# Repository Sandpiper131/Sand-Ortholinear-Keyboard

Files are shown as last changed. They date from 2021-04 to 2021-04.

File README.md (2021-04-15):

# [ Description ]
The Sand Ortholinear is a QWERTY style keyboard with 47 individually programmable keys. The
keyboard is powered by an ATMEGA32U4 microcontroller running the QMK open source keyboard
firmware. The goal of this project was to design a keyboard which is compact and durable while
having a simple case.

# [ Design Requirements ]
-Compact/Portable  
-Cherry MX Compatible  
-Ortholinear QWERTY (Grid) Layout with 2U spacebar  
-No visible components on top side of board  
-minimize trace presence on visible portions of top PCB  
-Sandwich style case PCB|ACRYLIC|PCB held together with M3 Screws  
-USB-C Connector  
-Sturdy Construction  

# [ Gallery ]
## Renders:
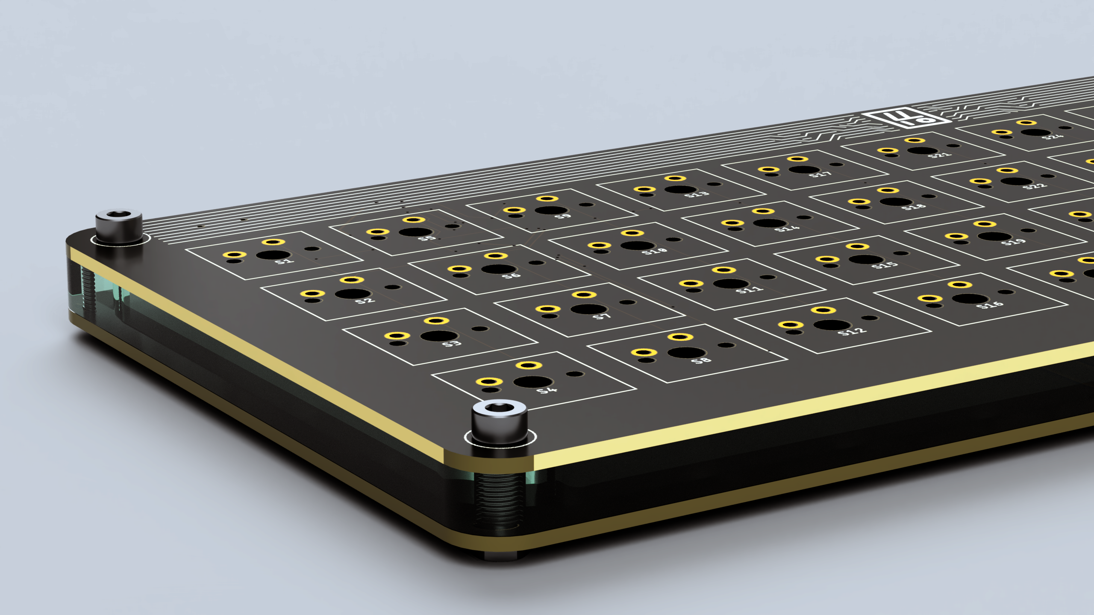
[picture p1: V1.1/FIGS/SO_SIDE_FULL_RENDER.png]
sand ortho render (side)
  
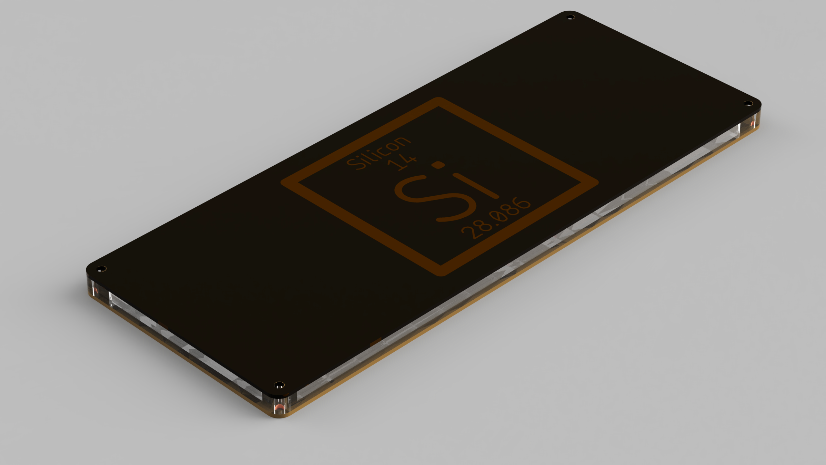
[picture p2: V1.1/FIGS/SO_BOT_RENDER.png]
sand ortho render (bottom)
  

## Schematics:
Sand Ortho V1.1 Schematic

## Board Layout:
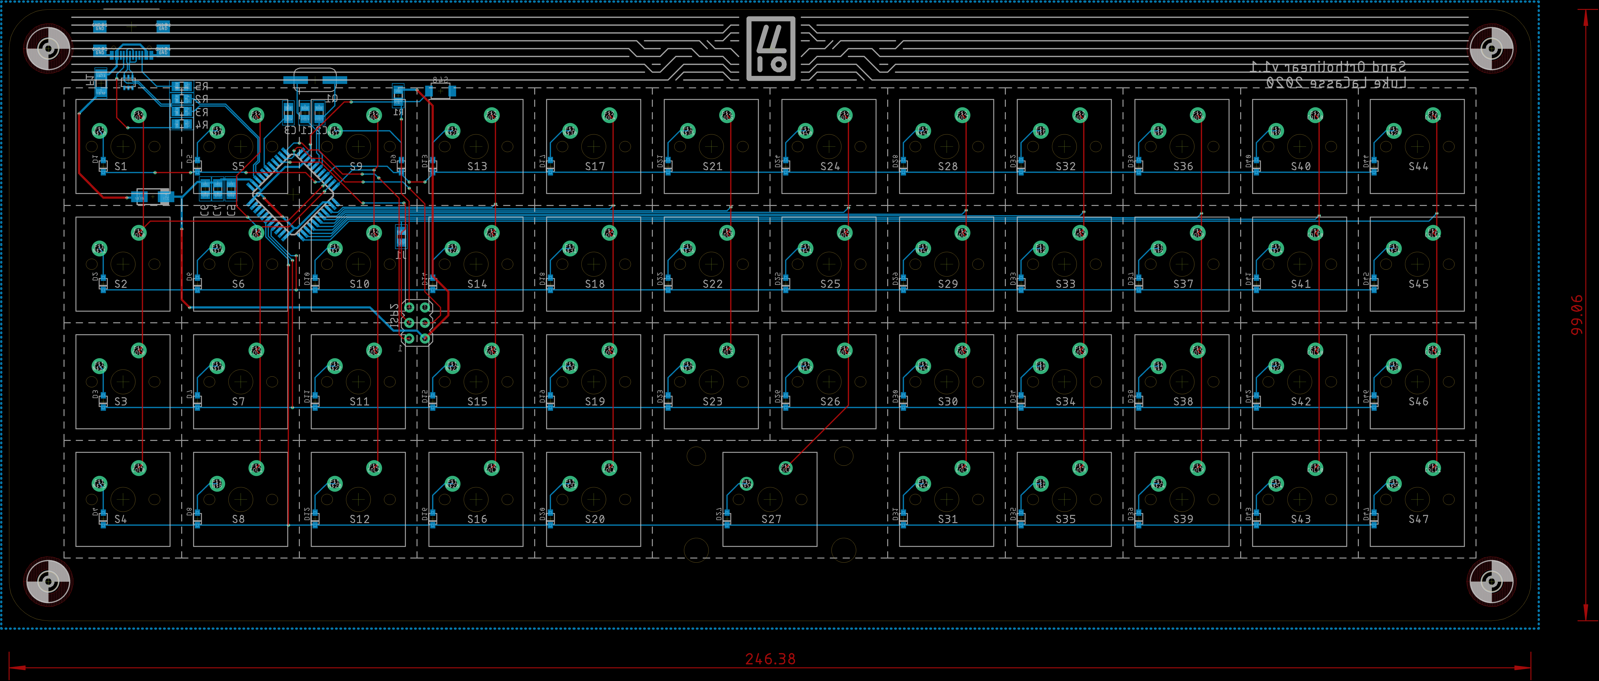
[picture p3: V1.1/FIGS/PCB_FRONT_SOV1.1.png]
Board Layout (Front 1)

Board Layout (Front 2)
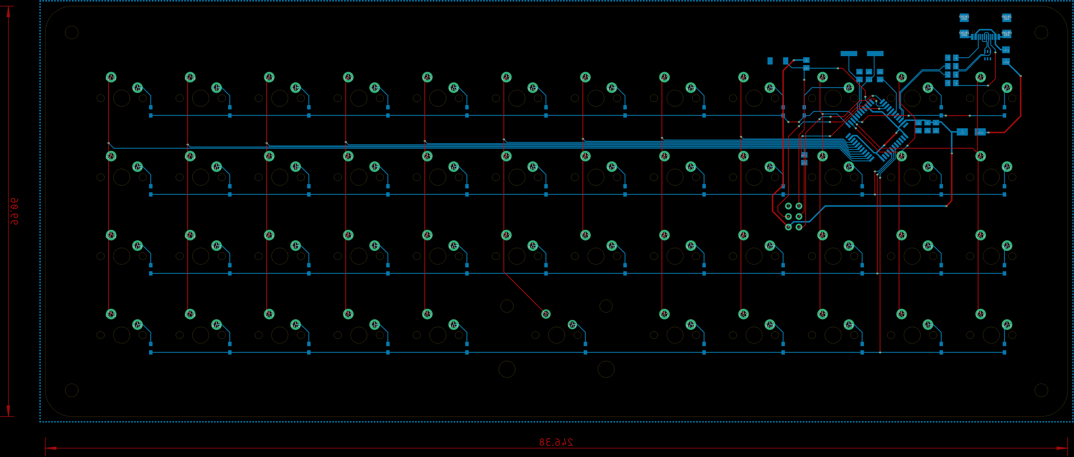
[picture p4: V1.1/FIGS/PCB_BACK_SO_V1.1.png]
Board Layout (Back 0)

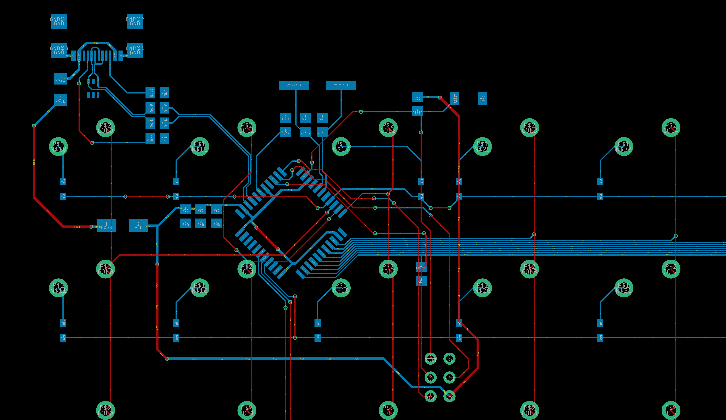
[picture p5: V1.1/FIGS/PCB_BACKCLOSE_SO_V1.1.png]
Board Close Up (Back)


## Pictures:
Sand Ortho Shot 2
Sand Ortho Shot 1

# [ Version History ]
## QMKDEVBRD
The QMK Development Board is a 3x3 Cherry MX-Compatible keypad used to
prototype a keyboard circuit prior to building a larger and more expensive keyboard. 
In addition to the basic microcontroller circuit with ISP and USB connectivity a 
prototyping area with breakouts for unused uC pins is included. Doing so 
makes this board not only a prototype for a final keyboard design, but also
a useful tool for contributing to the QMK Firmware project in the future.
The QMK Development Board functions as expected and works flawlessly with 
the QMK firmware. 

## Sand v1.0
Error in USB-C Circuit, no resistors for orientation, D+/D- not shorted 
to respective pair; USB connectivity non-functional. Added protection
circuit with Schottkey Diode and PTC fuse. Diodes are too small and
difficult to solder resulting in feedback in keyboard matrix. Crystal
Oscillator is also too small and impossible to solder by hand; Resolved
using a through hole crystal soldered onto pads. 

Changing focus to the mechanical/visual design of the keyboard is a simple
yet elegant PCB and Acrylic sandwich all held togetherwith M3 bolts and nuts.  
The resulting keyboard exceeded expectations and is very rigid, low-profile,
and provides ample protection from dust and debris.

## Sand v1.1
Added larger surface mount crystal oscillator and corrected above mentioned
flaws in the USB-C circuit. Opted not to change the diodes
as this was a minor revision and the part had already been ordered in excess.

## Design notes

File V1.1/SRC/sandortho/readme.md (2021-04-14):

# sandortho

sandortho

The sand ortholinear keyboard was inpired by silicon, the element used to make semiconductor materials. The keyboard has 47 keys laid out in an ortholinear grid with a 2U spacebar. The board can be assembled with standoffs in between the backplate, the keyboard can be as short as 7.2mm tall (excluding switches and keycpas) or as tall as ~9.5mm with a 1/4" piece of acrylic sandwiched in between. I worked on this project from the end of July 2020 to September 2020.

* Keyboard Maintainer: [Luke LaCasse](https://github.com/Sandpiper131)
* Hardware Supported: ATMEGA32-U4
* Hardware Availability: This is custom hardware and will not be run a second time, only five are in existence.

Make example for this keyboard (after setting up your build environment):

    make sandortho:default

See the [build environment setup](https://docs.qmk.fm/#/getting_started_build_tools) and the [make instructions](https://docs.qmk.fm/#/getting_started_make_guide) for more information. Brand new to QMK? Start with our [Complete Newbs Guide](https://docs.qmk.fm/#/newbs).

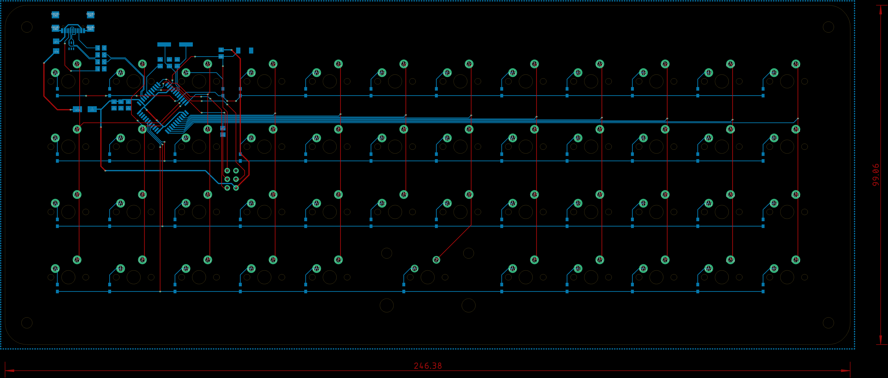
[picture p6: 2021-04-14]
V1.1/FIGS/PCB_FRONT1_SOV1.1.png

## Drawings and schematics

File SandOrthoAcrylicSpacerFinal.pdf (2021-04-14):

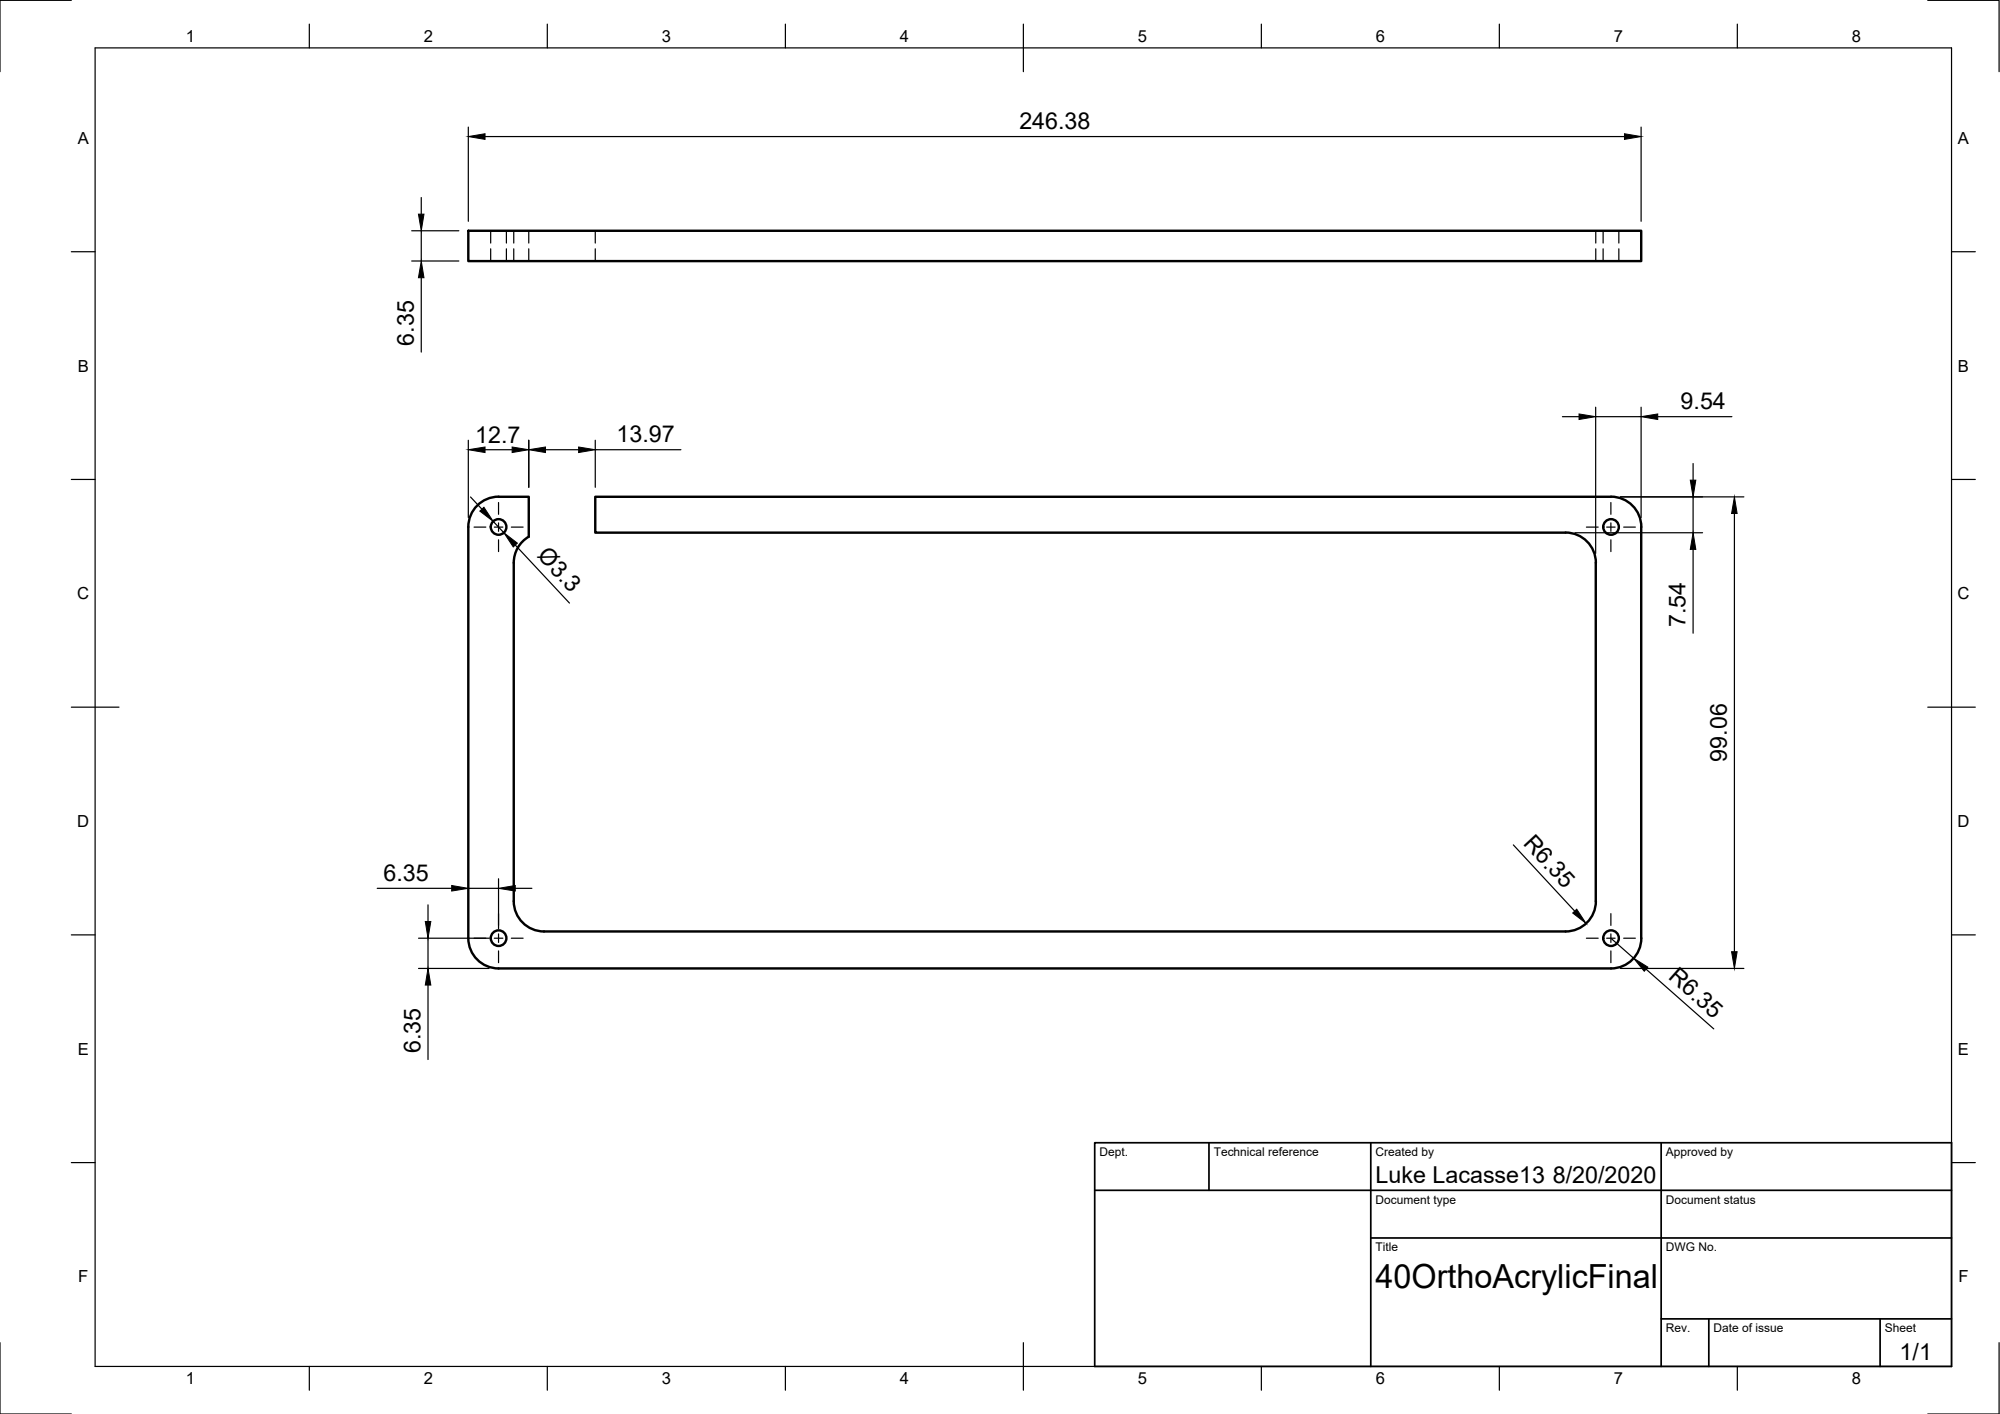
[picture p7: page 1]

Dept. | Technical reference | Created by Luke Lacasse13 8/20/2020 | Approved by

Document type | Document status

Title 40OrthoAcrylicFinal | DWG No.

Rev. | Date of issue | Sheet 1/1

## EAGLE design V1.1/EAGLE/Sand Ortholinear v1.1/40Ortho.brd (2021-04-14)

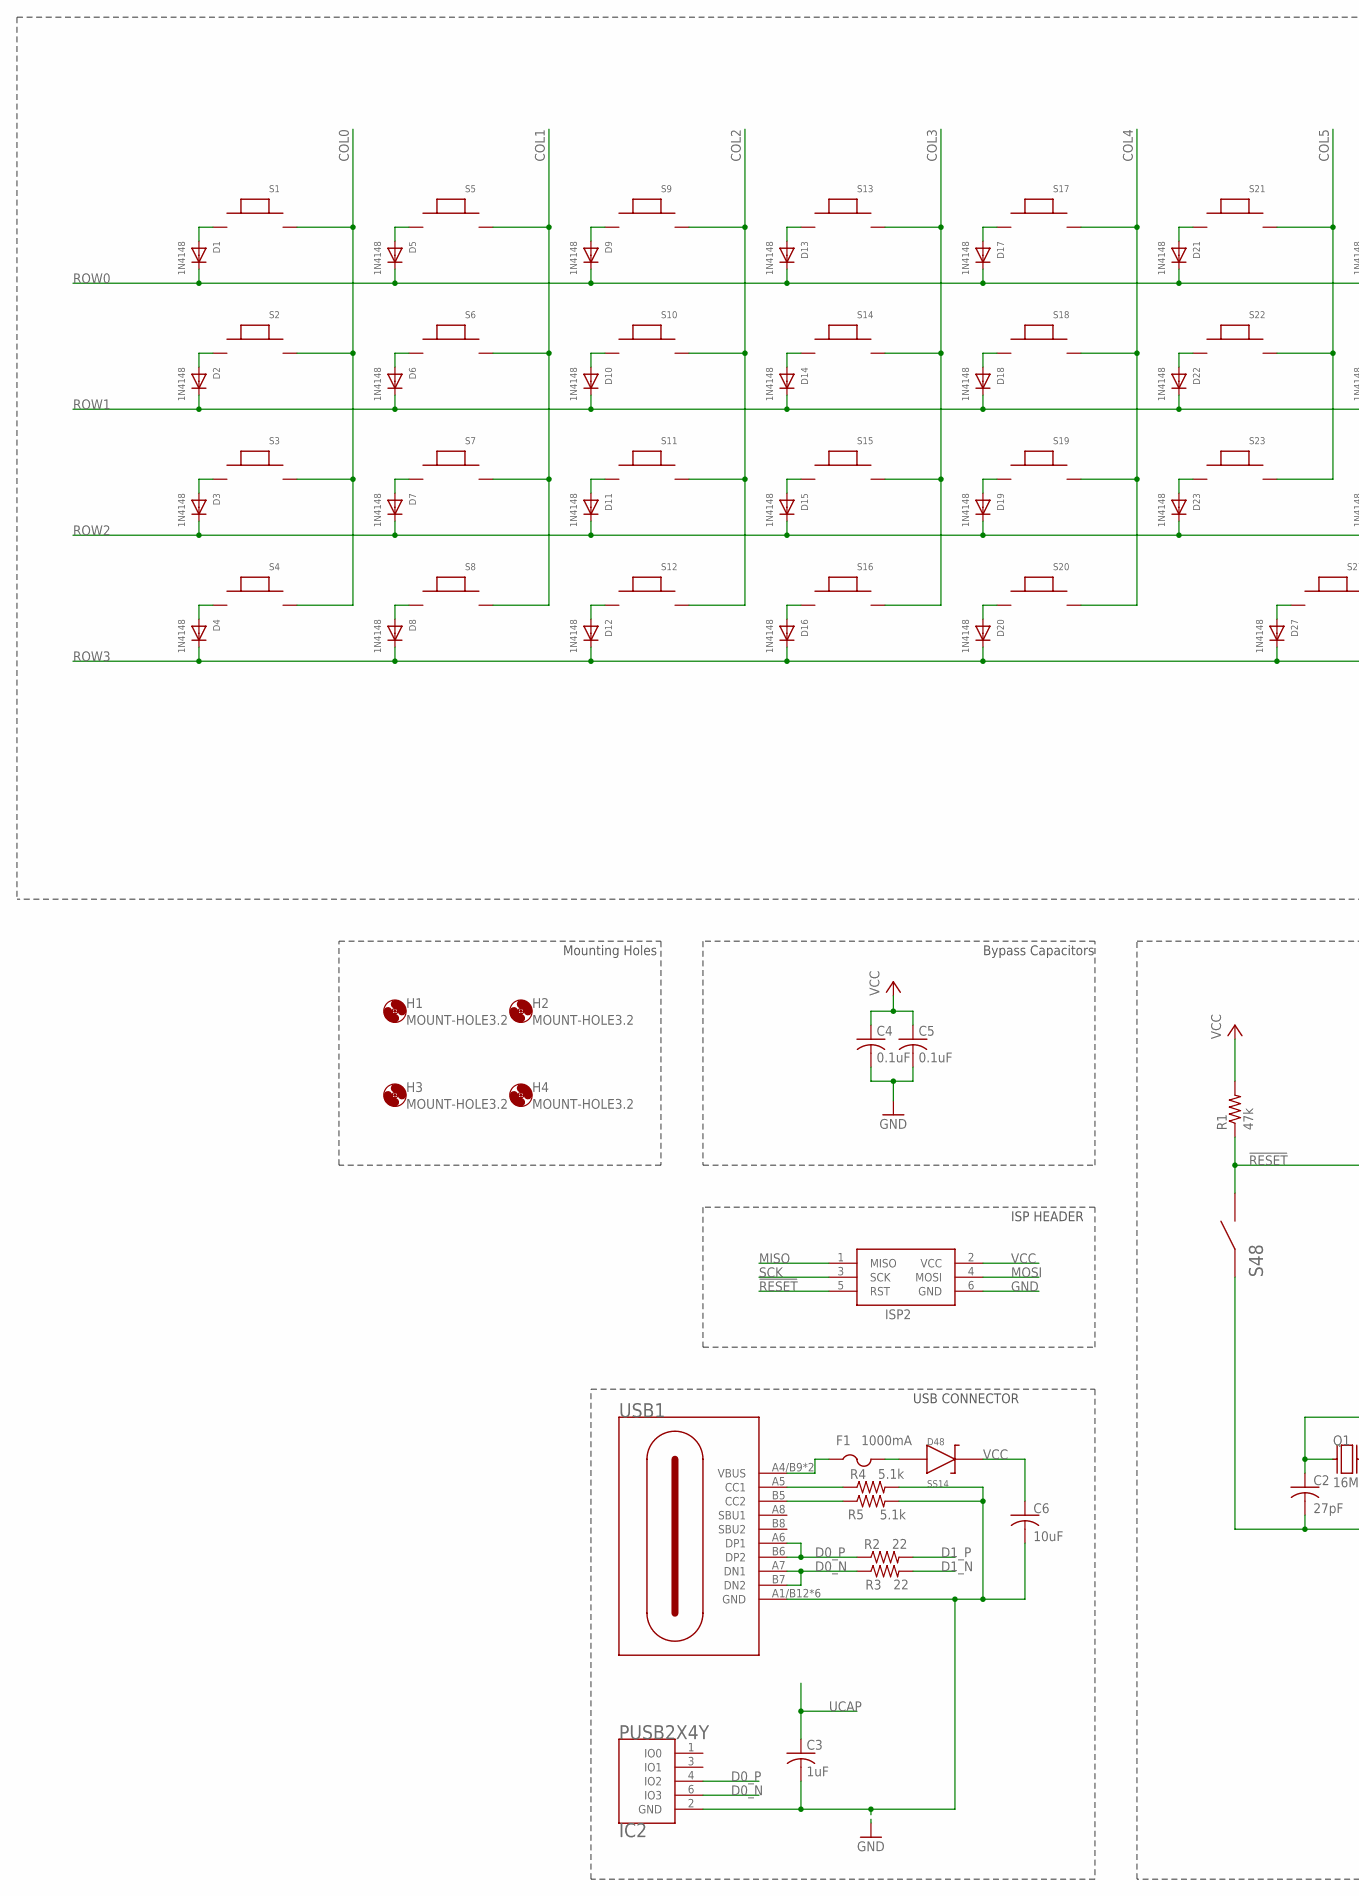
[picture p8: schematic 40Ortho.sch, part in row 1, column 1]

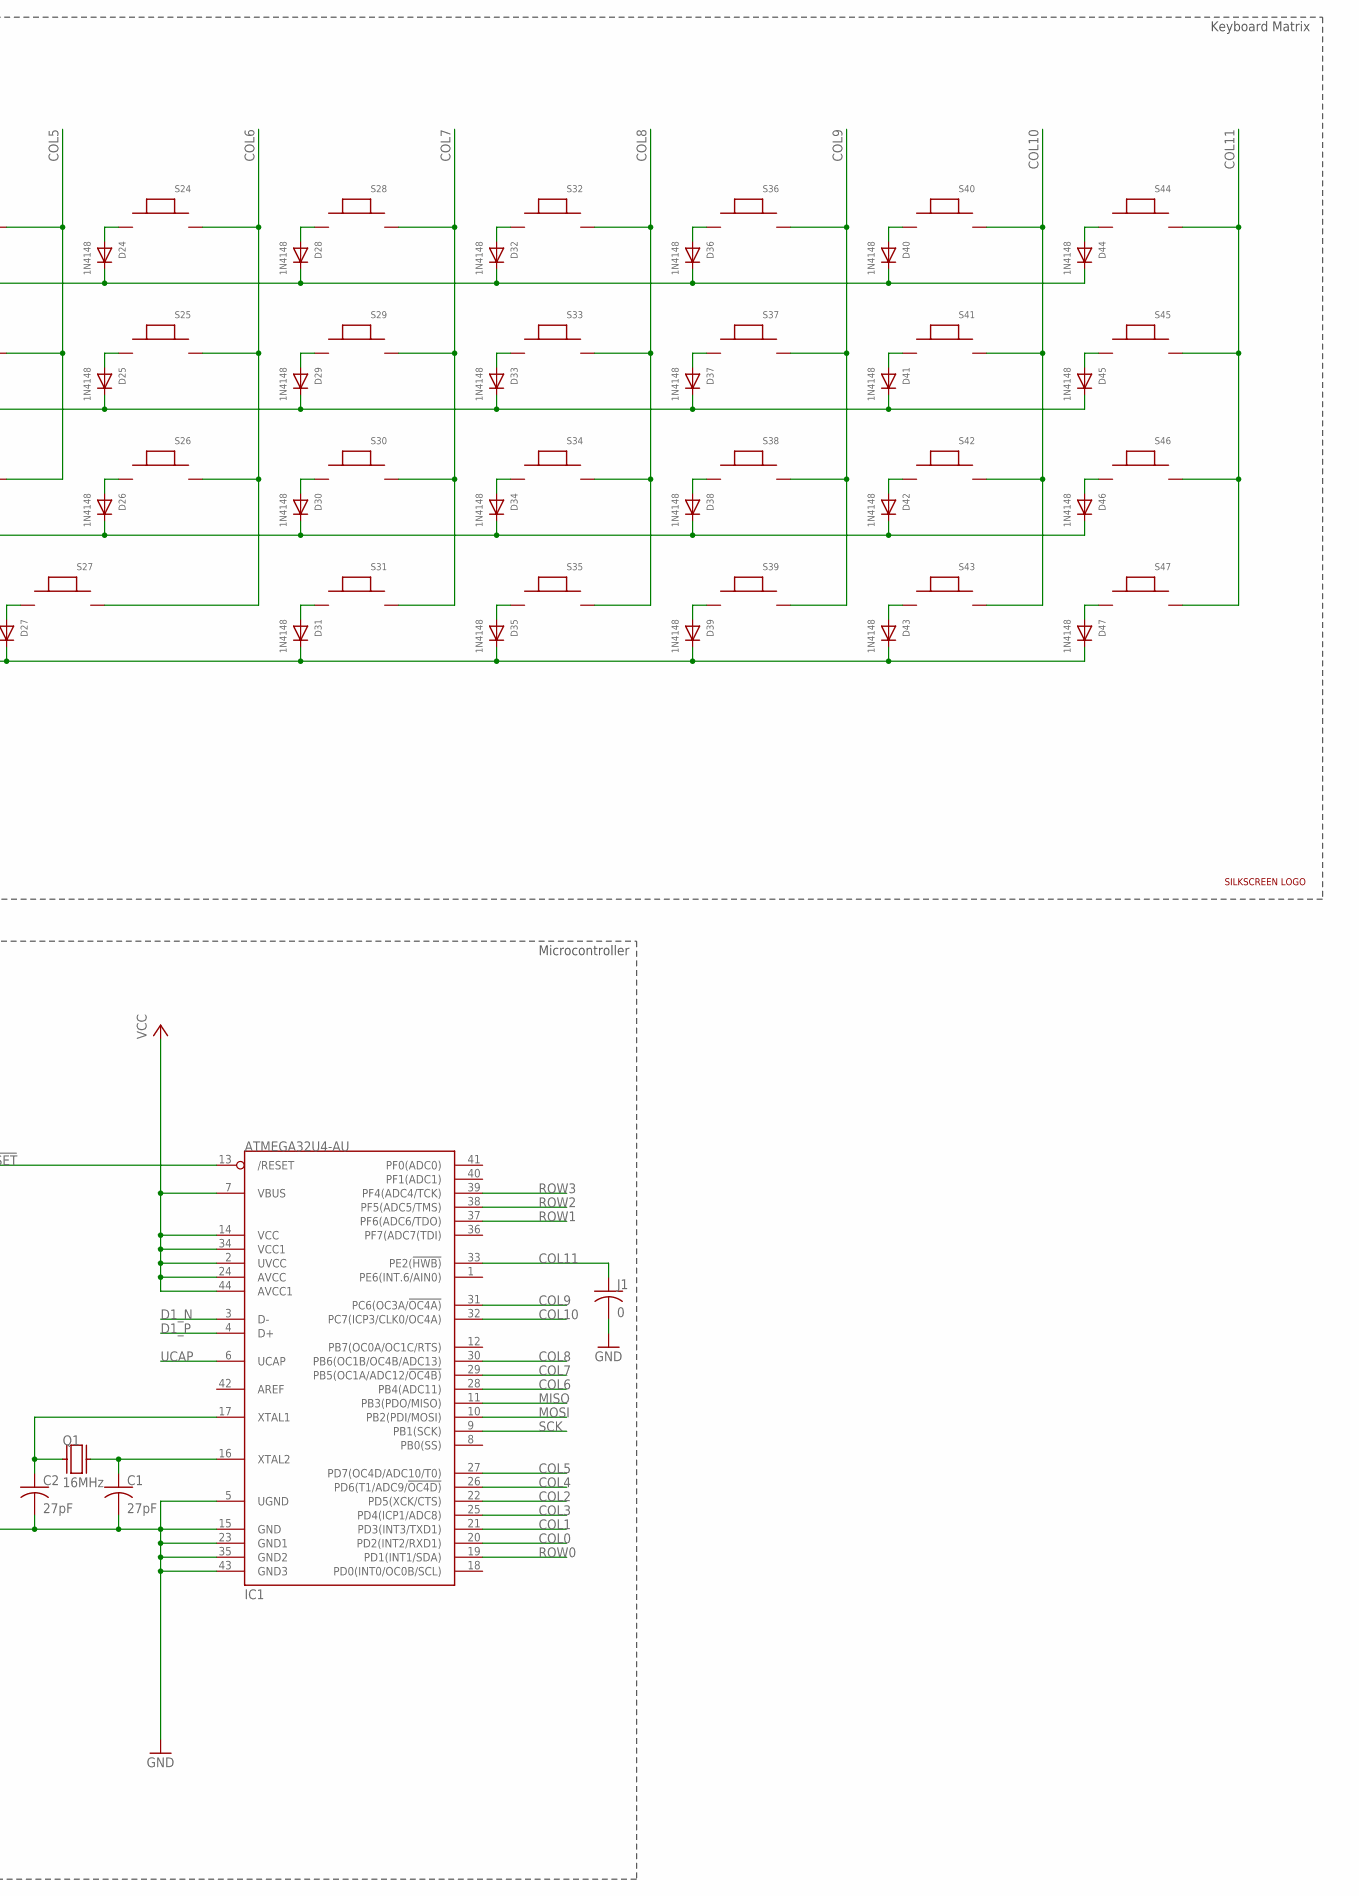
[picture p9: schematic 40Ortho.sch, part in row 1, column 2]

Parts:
C1, C2: 27pF; C0805
C3: 1uF; C0805
C4, C5: 0.1uF; C0805
C6: 10uF; C0805
D1, D2, D3, D4, D5, D6, D7, D8, D9, D10, D11, D12, D13, D14, D15, D16, D17, D18, D19, D20, D21, D22, D23, D24, D25, D26, D27, D28, D29, D30, D31, D32, D33, D34, D35, D36, D37, D38, D39, D40, D41, D42, D43, D44, D45, D46, D47: 1N4148; SOD-323F
D48: SS14; DO-214AC
F1: 1000mA; R1206
H1, H2, H3, H4: MOUNT-HOLE3.2; 3,2
IC1: ATMEGA32U4-AU; TQFP44
IC2: PUSB2X4Y; SOT363
ISP2: AVRISP-6; AVRISP
J1: 0; C0805
Q1: 16MHz; ABLS7M2
R1: 47k; R0805
R2, R3: 22; R0805
R4, R5: 5.1k; R0805
S1, S2, S3, S4, S5, S6, S7, S8, S9, S10, S11, S12, S13, S14, S15, S16, S17, S18, S19, S20, S21, S22, S23, S24, S25, S26, S28, S29, S30, S31, S32, S33, S34, S35, S36, S37, S38, S39, S40, S41, S42, S43, S44, S45, S46, S47: MX_SMD_1U; MX_SMD
S27: MX_SMD_2UH; MX_SMD2U
S48: B3U-1000P
U$1: LOGO
USB1: USBC_16PINSMD

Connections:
!RESET: IC1.13 (/RESET), ISP2.5 (RST), R1.1, S48.2
COL0: IC1.20 (PD2(INT2/RXD1)), S1.P$2, S2.P$2, S3.P$2, S4.P$2
COL1: IC1.21 (PD3(INT3/TXD1)), S5.P$2, S6.P$2, S7.P$2, S8.P$2
COL2: IC1.22 (PD5(XCK/CTS)), S9.P$2, S10.P$2, S11.P$2, S12.P$2
COL3: IC1.25 (PD4(ICP1/ADC8)), S13.P$2, S14.P$2, S15.P$2, S16.P$2
COL4: IC1.26 (PD6(T1/ADC9/!OC4D)), S17.P$2, S18.P$2, S19.P$2, S20.P$2
COL5: IC1.27 (PD7(OC4D/ADC10/T0)), S21.P$2, S22.P$2, S23.P$2
COL6: IC1.28 (PB4(ADC11)), S24.P$2, S25.P$2, S26.P$2, S27.P$2
COL7: IC1.29 (PB5(OC1A/ADC12/!OC4B)), S28.P$2, S29.P$2, S30.P$2, S31.P$2
COL8: IC1.30 (PB6(OC1B/OC4B/ADC13)), S32.P$2, S33.P$2, S34.P$2, S35.P$2
COL9: IC1.31 (PC6(OC3A/!OC4A)), S36.P$2, S37.P$2, S38.P$2, S39.P$2
COL10: IC1.32 (PC7(ICP3/CLK0/OC4A)), S40.P$2, S41.P$2, S42.P$2, S43.P$2
COL11: IC1.33 (PE2(!HWB)), J1.1, S44.P$2, S45.P$2, S46.P$2, S47.P$2
D0_N: IC2.6 (IO3), R3.1, USB1.A7 (DN1), USB1.B7 (DN2)
D0_P: IC2.4 (IO2), R2.1, USB1.A6 (DP1), USB1.B6 (DP2)
D1_N: IC1.3 (D-), R3.2
D1_P: IC1.4 (D+), R2.2
GND: C1.2, C2.2, C3.2, C4.2, C5.2, C6.2, IC1.5 (UGND), IC1.15 (GND), IC1.23 (GND1), IC1.35 (GND2), IC1.43 (GND3), IC2.2 (GND), ISP2.6 (GND), J1.2, R4.2, R5.2, S48.1, USB1.A1/B12 (GND), USB1.B1/A12 (GND), USB1.GND@1 (GND), USB1.GND@2 (GND), USB1.GND@3 (GND), USB1.GND@4 (GND)
MISO: IC1.11 (PB3(PDO/MISO)), ISP2.1 (MISO)
MOSI: IC1.10 (PB2(PDI/MOSI)), ISP2.4 (MOSI)
unnamed: D32.A, S32.P$1
unnamed: D33.A, S33.P$1
unnamed: D34.A, S34.P$1
unnamed: D35.A, S35.P$1
unnamed: D36.A, S36.P$1
unnamed: D37.A, S37.P$1
unnamed: D38.A, S38.P$1
unnamed: D8.A, S8.P$1
unnamed: D40.A, S40.P$1
unnamed: D1.A, S1.P$1
unnamed: D2.A, S2.P$1
unnamed: D3.A, S3.P$1
unnamed: D4.A, S4.P$1
unnamed: D41.A, S41.P$1
unnamed: D5.A, S5.P$1
unnamed: D6.A, S6.P$1
unnamed: D9.A, S9.P$1
unnamed: D10.A, S10.P$1
unnamed: D7.A, S7.P$1
unnamed: D12.A, S12.P$1
unnamed: D42.A, S42.P$1
unnamed: D11.A, S11.P$1
unnamed: F1.1, USB1.A4/B9 (VBUS), USB1.B4/A9 (VBUS)
unnamed: D39.A, S39.P$1
unnamed: D13.A, S13.P$1
unnamed: D14.A, S14.P$1
unnamed: D15.A, S15.P$1
unnamed: D16.A, S16.P$1
unnamed: D44.A, S44.P$1
unnamed: D17.A, S17.P$1
unnamed: D18.A, S18.P$1
unnamed: D19.A, S19.P$1
unnamed: D20.A, S20.P$1
unnamed: D45.A, S45.P$1
unnamed: D21.A, S21.P$1
unnamed: D22.A, S22.P$1
unnamed: D23.A, S23.P$1
unnamed: D48.1 (ANODE), F1.2
unnamed: D46.A, S46.P$1
unnamed: D24.A, S24.P$1
unnamed: D25.A, S25.P$1
unnamed: D26.A, S26.P$1
unnamed: R4.1, USB1.A5 (CC1)
unnamed: D28.A, S28.P$1
unnamed: D29.A, S29.P$1
unnamed: D30.A, S30.P$1
unnamed: D31.A, S31.P$1
unnamed: R5.1, USB1.B5 (CC2)
unnamed: D27.A, S27.P$1
unnamed: D43.A, S43.P$1
unnamed: D47.A, S47.P$1
ROW0: D1.C, D5.C, D9.C, D13.C, D17.C, D21.C, D24.C, D28.C, D32.C, D36.C, D40.C, D44.C, IC1.19 (PD1(INT1/SDA))
ROW1: D2.C, D6.C, D10.C, D14.C, D18.C, D22.C, D25.C, D29.C, D33.C, D37.C, D41.C, D45.C, IC1.37 (PF6(ADC6/TDO))
ROW2: D3.C, D7.C, D11.C, D15.C, D19.C, D23.C, D26.C, D30.C, D34.C, D38.C, D42.C, D46.C, IC1.38 (PF5(ADC5/TMS))
ROW3: D4.C, D8.C, D12.C, D16.C, D20.C, D27.C, D31.C, D35.C, D39.C, D43.C, D47.C, IC1.39 (PF4(ADC4/TCK))
SCK: IC1.9 (PB1(SCK)), ISP2.3 (SCK)
UCAP: C3.1, IC1.6 (UCAP)
VCC: C4.1, C5.1, C6.1, D48.2 (CATHODE), IC1.2 (UVCC), IC1.7 (VBUS), IC1.14 (VCC), IC1.24 (AVCC), IC1.34 (VCC1), IC1.44 (AVCC1), ISP2.2 (VCC), R1.2
XTAL1: C2.1, IC1.17 (XTAL1), Q1.X1
XTAL2: C1.1, IC1.16 (XTAL2), Q1.X2

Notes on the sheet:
USB CONNECTOR
ISP HEADER
Microcontroller
Bypass Capacitors
Keyboard Matrix
Mounting Holes

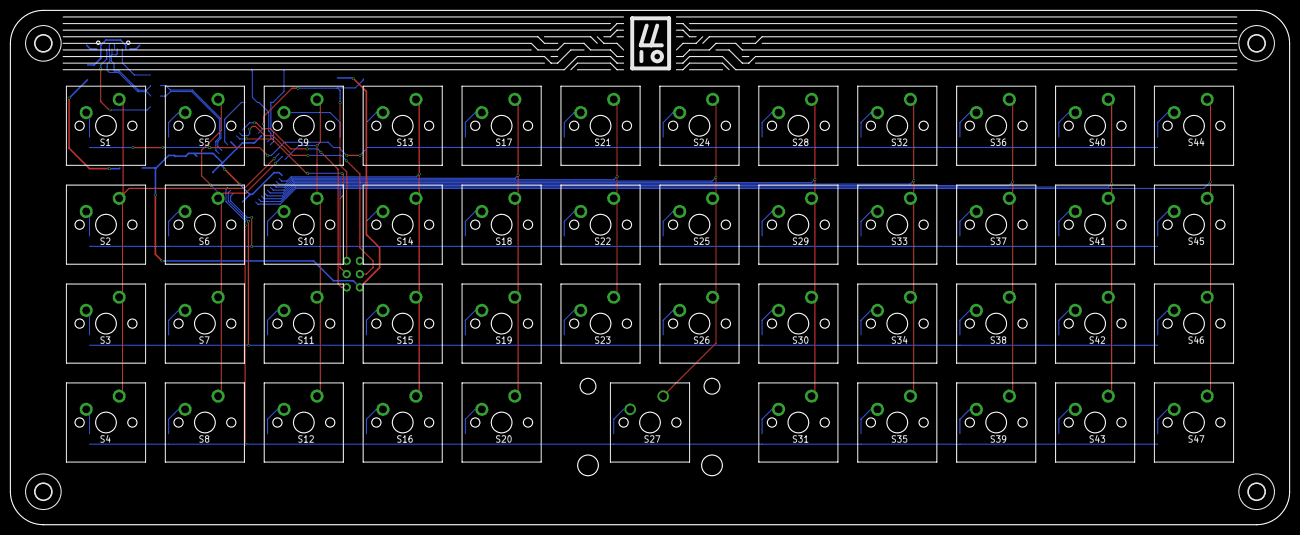
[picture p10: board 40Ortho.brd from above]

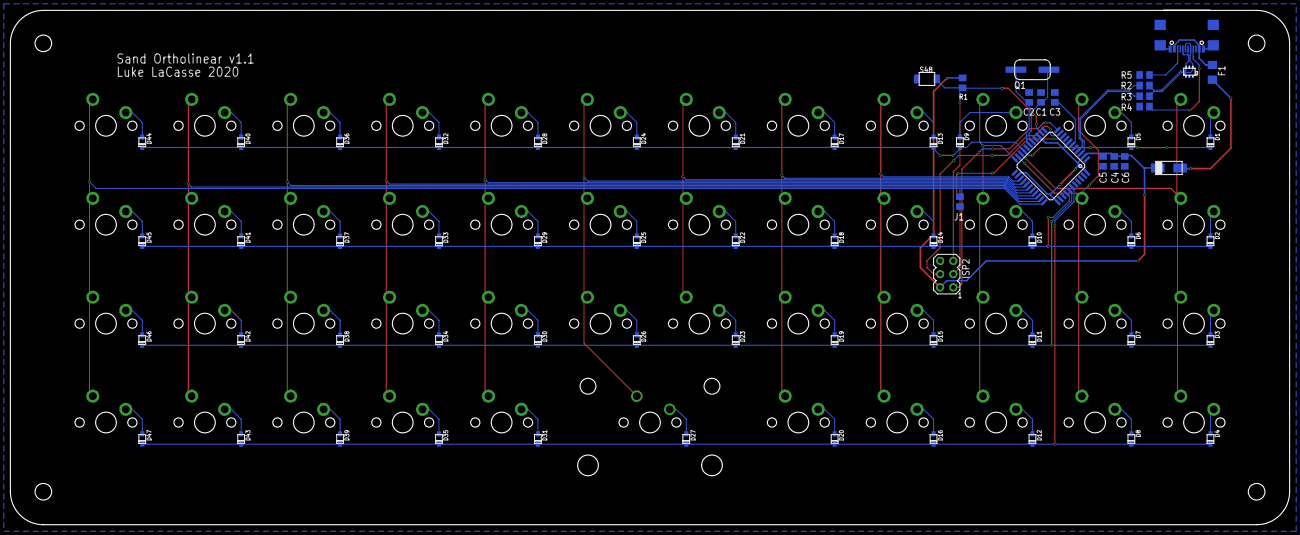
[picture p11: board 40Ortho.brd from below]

Board: 2 copper layers, 246.4 x 99.1 mm, 119 parts (67 on the bottom side), 80 nets.
